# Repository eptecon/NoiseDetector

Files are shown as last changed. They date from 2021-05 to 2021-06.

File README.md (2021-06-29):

NoiseDetector: Connected Noise Detector
======

Noise Detector is a simple device for lowering noise levels in the office or public places. It monitors noise level and alarms when it gets too loud. It is also connected to cloud over Wireless LAN for providing noise data for further analytics
It is easy to install and use in every environment.

### Hardware

Noise Detector is based on a MEMS microphone that measures intensity of noise and ESP32 microcontroller that monitors the noise level and sends measured results to cloud.
The user can adjust a threshold for the detection. The Noise Detector can indicate alarms if it is too loud using onboard buzzer and LED.

### Firmware

The firmware consists of a RTOS and applications for measuring and analysing of noise level as well as sending information to cloud. It connects to a cloud and provides noise data over MQTT.

### Usage

No software installation is required. Just turn on and connect to your WLAN Network. Immediately after connecting, the device starts to send the measured noise level 
to the cloud service ([GlueLogics](https://github.com/eptecon/gluelogics)) enabling analytics for your working environment, even without invasive notifications.

---

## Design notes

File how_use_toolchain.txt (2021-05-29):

ls /dev/cu.*

/dev/ttyUSB0 - UNIX
/dev/cu.SLAB_USBtoUART - MAC

==========
To exit the monitor use shortcut Ctrl+] --- CTRL + ALT + 6
Ctrl-T Ctrl-H will display a help menu with all other keyboard shortcuts.
Any other key apart from Ctrl-] and Ctrl-T is sent through the serial port.
============

Now you can build and flash the application. Run:

make flash

This will compile the application and all the ESP-IDF components, generate bootloader, partition table, and application binaries, and flash these binaries to your ESP32 board.

To see if “hello_world” application is indeed running, type 
make monitor. 
This command is launching IDF Monitor application

To exit monitor use shortcut Ctrl+]. 

To execute make flash and make monitor in one shoot type 
make flash monitor.

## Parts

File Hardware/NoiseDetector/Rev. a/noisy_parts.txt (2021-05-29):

Stückliste exportiert aus /home/erwin/Projekte/eagle/GlueSensors/NoiseSensor/Rev. a/noisy.sch am 11.07.18 14:24

Part Value                   Device                  Package                Description                                                                                       DATASHEET                                     DESCRIPTION DIGIKEY     ELEMENT14 MF      MPN          OC_FARNELL OC_NEWARK OTHER PACKAGE PROD_ID    SF_SKU    SUPPLIER  URL                                                                                            VALUE     
B1   BUZZER-8540S            BUZZER-8540S            BUZZER-8540S                                                                                                                                                                                                                                                                                                                                                                                             
BT1                          BATTERY-AA              BATTERY-AA             Battery - Single Cell                                                                                                                                                                                                                     BATT-08316 PRT-07949                                                                                                                    
C1   1uF/10V(10%)            C-EUC0603               C0603                  CAPACITOR, European symbol                                                                                                                                                                                                                                                                                                                                                        
C2   100nF/10V(10%)          C-EUC0603               C0603                  CAPACITOR, European symbol                                                                                                                                                                                                                                                                                                                                                        
C3   1uF/10V(10%)            C-EUC0603               C0603                  CAPACITOR, European symbol                                                                                                                                                                                                                                                                                                                                                        
C4   1uF/10V(10%)            C-EUC0603               C0603                  CAPACITOR, European symbol                                                                                                                                                                                                                                                                                                                                                        
C5   100nF/10V(10%)          C-EUC0603               C0603                  CAPACITOR, European symbol                                                                                                                                                                                                                                                                                                                                                        
C6   100nF/10V(10%)          C-EUC0603               C0603                  CAPACITOR, European symbol                                                                                                                                                                                                                                                                                                                                                        
C7   100nF/10V(10%)          C-EUC0603               C0603                  CAPACITOR, European symbol                                                                                                                                                                                                                                                                                                                                                        
C8   100nF/10V(10%)          C-EUC0603               C0603                  CAPACITOR, European symbol                                                                                                                                                                                                                                                                                                                                                        
C9   100nF/10V(10%)          C-EUC0603               C0603                  CAPACITOR, European symbol                                                                                                                                                                                                                                                                                                                                                        
C10  100nF/10V(10%)          C-EUC0603               C0603                  CAPACITOR, European symbol                                                                                                                                                                                                                                                                                                                                                        
C11  100nF/10V(10%)          C-EUC0603               C0603                  CAPACITOR, European symbol                                                                                                                                                                                                                                                                                                                                                        
C12  100nF/10V(10%)          C-EUC0603               C0603                  CAPACITOR, European symbol                                                                                                                                                                                                                                                                                                                                                        
C13  100nF/10V(10%)          C-EUC0603               C0603                  CAPACITOR, European symbol                                                                                                                                                                                                                                                                                                                                                        
C14  100n/10V(10%)           C-EUC0603               C0603                  CAPACITOR, European symbol                                                                                                                                                                                                                                                                                                                                                        
C15  1uF/10V(10%)            C-EUC0603               C0603                  CAPACITOR, European symbol                                                                                                                                                                                                                                                                                                                                                        
C16  10uF/25V(10%)           C-EUC0603               C0603                  CAPACITOR, European symbol                                                                                                                                                                                                                                                                                                                                                        
C17  10uF/25V(10%)           C-EUC0603               C0603                  CAPACITOR, European symbol                                                                                                                                                                                                                                                                                                                                                        
C18  1uF/25V(10%)            C-EUC0603               C0603                  CAPACITOR, European symbol                                                                                                                                                                                                                                                                                                                                                        
C19  10uF/25V(10%)           C-EUC0603               C0603                  CAPACITOR, European symbol                                                                                                                                                                                                                                                                                                                                                        
C20  10uF/10V(10%)           C-EUC0603               C0603                  CAPACITOR, European symbol                                                                                                                                                                                                                                                                                                                                                        
C21  100nF/25V(10%)          C-EUC0603               C0603                  CAPACITOR, European symbol                                                                                                                                                                                                                                                                                                                                                        
C22  10uF/25V(10%)           C-EUC0603               C0603                  CAPACITOR, European symbol                                                                                                                                                                                                                                                                                                                                                        
C23  100nF/25V(10%)          C-EUC0603               C0603                  CAPACITOR, European symbol                                                                                                                                                                                                                                                                                                                                                        
C24  100nF/10V(10%)          C-EUC0603               C0603                  CAPACITOR, European symbol                                                                                                                                                                                                                                                                                                                                                        
C25  10uF/10V(10%)           C-EUC0603               C0603                  CAPACITOR, European symbol                                                                                                                                                                                                                                                                                                                                                        
CN3                          USBMINIBLARGE           USB-MINIB_LARGER       USB Connectors                                                                                                                                                                                                                                                                                                                                                                    
D1   MBR120                  MBR0520LT               SOD123                 SCHOTTKY BARRIER RECTIFIER                                                                                                                                                                                                                                                                                                                                                        
D2   4148                    DIODE-BAS16J            SOD-323                Diode                                                                                                                                                                                                                                     DIO-09646                                                                                                                     250mA/100V
H1   STAND-OFF               STAND-OFF               STAND-OFF              Stand Off                                                                                                                                                                                                                                                                                                                                                                         
H2   STAND-OFF               STAND-OFF               STAND-OFF              Stand Off                                                                                                                                                                                                                                                                                                                                                                         
H3   STAND-OFF               STAND-OFF               STAND-OFF              Stand Off                                                                                                                                                                                                                                                                                                                                                                         
LED1 GREEN PWR               LED0805_NOOUTLINE       CHIPLED_0805_NOOUTLINE LED                                                                                                                                                                                                                                                                                                                                                                               
LED2 ORANGE                  LED0805_NOOUTLINE       CHIPLED_0805_NOOUTLINE LED                                                                                                                                                                                                                                                                                                                                                                               
LED3 SML-LX0404              SML-LX0404              LED_RGB                                                                                                                                                                                                                                                                                                                                                                                                  
Q1   N-CHANNEL-MOSFET-BSS138 N-CHANNEL-MOSFET-BSS138 SOT23-3                N-Channel MOSFET Mode Field Effect Transistor                                                     http://www.fairchildsemi.com/ds/BS/BSS138.pdf             BSS138TR-ND 2323154                                                                                          http://au.element14.com/fairchild-semiconductor/bss138/mosfet-n-ch-50v-220ma-sot-23/dp/2323154           
Q2   DMP2045U                MOSFET-P                SOT23-R                P-Channel Mosfet                                                                                                                                                                                                                                                                                                                                                                  
Q3   mmbt2222                TRANSISTOR_NPN          SOT23-R                NPN Transistor                                                                                                                                                                                                                                                                                                                                                                    
Q4   mmbt2222                TRANSISTOR_NPN          SOT23-R                NPN Transistor                                                                                                                                                                                                                                                                                                                                                                    
Q5   DMN2058U                MOSFET-NREFLOW          SOT23-R                N-Channel Mosfet                                                                                                                                                                                                                                                                                                                                                                  
R1   1M(1%)                  R-EU_R0603              R0603                  RESISTOR, European symbol                                                                                                                                                                                                                                                                                                                                                         
R2   1M(1%)                  R-EU_R0603              R0603                  RESISTOR, European symbol                                                                                                                                                                                                                                                                                                                                                         
R3   390(1%)                 R-EU_R0603              R0603                  RESISTOR, European symbol                                                                                                                                                                                                                                                                                                                                                         
R4   10k(1%)                 R-EU_R0603              R0603                  RESISTOR, European symbol                                                                                                                                                                                                                                                                                                                                                         
R5   120k(1%)                R-EU_R0603              R0603                  RESISTOR, European symbol                                                                                                                                                                                                                                                                                                                                                         
R6   10k(1%)                 R-EU_R0603              R0603                  RESISTOR, European symbol                                                                                                                                                                                                                                                                                                                                                         
R7   120k(1%)                R-EU_R0603              R0603                  RESISTOR, European symbol                                                                                                                                                                                                                                                                                                                                                         
R8   100k(1%)                R-EU_R0603              R0603                  RESISTOR, European symbol                                                                                                                                                                                                                                                                                                                                                         
R9   100k(1%)                R-EU_R0603              R0603                  RESISTOR, European symbol                                                                                                                                                                                                                                                                                                                                                         
R10  100k(1%)                R-EU_R0603              R0603                  RESISTOR, European symbol                                                                                                                                                                                                                                                                                                                                                         
R11  470(1%)                 R-EU_R0603              R0603                  RESISTOR, European symbol                                                                                                                                                                                                                                                                                                                                                         
R12  2.2k(1%)                R-EU_R0603              R0603                  RESISTOR, European symbol                                                                                                                                                                                                                                                                                                                                                         
R13  1k(1%)                  R-EU_R0603              R0603                  RESISTOR, European symbol                                                                                                                                                                                                                                                                                                                                                         
R14  10k(1%)                 R-EU_R0603              R0603                  RESISTOR, European symbol                                                                                                                                                                                                                                                                                                                                                         
R15  0(1%)                   R-EU_R0603              R0603                  RESISTOR, European symbol                                                                                                                                                                                                                                                                                                                                                         
R16  10k(1%)                 R-EU_R0603              R0603                  RESISTOR, European symbol                                                                                                                                                                                                                                                                                                                                                         
R17  0(1%)                   R-EU_R0603              R0603                  RESISTOR, European symbol                                                                                                                                                                                                                                                                                                                                                         
R18  10k(1%)                 R-EU_R0603              R0603                  RESISTOR, European symbol                                                                                                                                                                                                                                                                                                                                                         
R19  100k(1%)                R-EU_R0603              R0603                  RESISTOR, European symbol                                                                                                                                                                                                                                                                                                                                                         
R20  100k(1%)                R-EU_R0603              R0603                  RESISTOR, European symbol                                                                                                                                                                                                                                                                                                                                                         
R21  100k(1%)                R-EU_R0603              R0603                  RESISTOR, European symbol                                                                                                                                                                                                                                                                                                                                                         
R22  100k(1%)                R-EU_R0603              R0603                  RESISTOR, European symbol                                                                                                                                                                                                                                                                                                                                                         
R23  10k(1%)                 R-EU_R0603              R0603                  RESISTOR, European symbol                                                                                                                                                                                                                                                                                                                                                         
R24  10k(1%)                 R-EU_R0603              R0603                  RESISTOR, European symbol
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

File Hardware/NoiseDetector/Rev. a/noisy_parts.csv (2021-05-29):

Part | Value | Device | Package | Description | DATASHEET | DESCRIPTION | DIGIKEY | ELEMENT14 | MF | MPN | OC_FARNELL | OC_NEWARK | OTHER | PACKAGE | PROD_ID | SF_SKU | SUPPLIER | URL | VALUE
B1 | BUZZER-8540S | BUZZER-8540S | BUZZER-8540S
BT1 |  | BATTERY-AA | BATTERY-AA | Battery - Single Cell |  |  |  |  |  |  |  |  |  |  | BATT-08316 | PRT-07949
C1 | 1uF/10V(10%) | C-EUC0603 | C0603 | CAPACITOR, European symbol
C2 | 100nF/10V(10%) | C-EUC0603 | C0603 | CAPACITOR, European symbol
C3 | 1uF/10V(10%) | C-EUC0603 | C0603 | CAPACITOR, European symbol
C4 | 1uF/10V(10%) | C-EUC0603 | C0603 | CAPACITOR, European symbol
C5 | 100nF/10V(10%) | C-EUC0603 | C0603 | CAPACITOR, European symbol
C6 | 100nF/10V(10%) | C-EUC0603 | C0603 | CAPACITOR, European symbol
C7 | 100nF/10V(10%) | C-EUC0603 | C0603 | CAPACITOR, European symbol
C8 | 100nF/10V(10%) | C-EUC0603 | C0603 | CAPACITOR, European symbol
C9 | 100nF/10V(10%) | C-EUC0603 | C0603 | CAPACITOR, European symbol
C10 | 100nF/10V(10%) | C-EUC0603 | C0603 | CAPACITOR, European symbol
C11 | 100nF/10V(10%) | C-EUC0603 | C0603 | CAPACITOR, European symbol
C12 | 100nF/10V(10%) | C-EUC0603 | C0603 | CAPACITOR, European symbol
C13 | 100nF/10V(10%) | C-EUC0603 | C0603 | CAPACITOR, European symbol
C14 | 100n/10V(10%) | C-EUC0603 | C0603 | CAPACITOR, European symbol
C15 | 1uF/10V(10%) | C-EUC0603 | C0603 | CAPACITOR, European symbol
C16 | 10uF/25V(10%) | C-EUC0603 | C0603 | CAPACITOR, European symbol
C17 | 10uF/25V(10%) | C-EUC0603 | C0603 | CAPACITOR, European symbol
C18 | 1uF/25V(10%) | C-EUC0603 | C0603 | CAPACITOR, European symbol
C19 | 10uF/25V(10%) | C-EUC0603 | C0603 | CAPACITOR, European symbol
C20 | 10uF/10V(10%) | C-EUC0603 | C0603 | CAPACITOR, European symbol
C21 | 100nF/25V(10%) | C-EUC0603 | C0603 | CAPACITOR, European symbol
C22 | 10uF/25V(10%) | C-EUC0603 | C0603 | CAPACITOR, European symbol
C23 | 100nF/25V(10%) | C-EUC0603 | C0603 | CAPACITOR, European symbol
C24 | 100nF/10V(10%) | C-EUC0603 | C0603 | CAPACITOR, European symbol
C25 | 10uF/10V(10%) | C-EUC0603 | C0603 | CAPACITOR, European symbol
CN3 |  | USBMINIBLARGE | USB-MINIB_LARGER | USB Connectors
D1 | MBR120 | MBR0520LT | SOD123 | SCHOTTKY BARRIER RECTIFIER
D2 | 4148 | DIODE-BAS16J | SOD-323 | Diode |  |  |  |  |  |  |  |  |  |  | DIO-09646 |  |  |  | 250mA/100V
H1 | STAND-OFF | STAND-OFF | STAND-OFF | Stand Off
H2 | STAND-OFF | STAND-OFF | STAND-OFF | Stand Off
H3 | STAND-OFF | STAND-OFF | STAND-OFF | Stand Off
LED1 | GREEN PWR | LED0805_NOOUTLINE | CHIPLED_0805_NOOUTLINE | LED
LED2 | ORANGE | LED0805_NOOUTLINE | CHIPLED_0805_NOOUTLINE | LED
LED3 | SML-LX0404 | SML-LX0404 | LED_RGB
Q1 | N-CHANNEL-MOSFET-BSS138 | N-CHANNEL-MOSFET-BSS138 | SOT23-3 | N-Channel MOSFET Mode Field Effect Transistor | http://www.fairchildsemi.com/ds/BS/BSS138.pdf |  | BSS138TR-ND | 2323154 |  |  |  |  |  |  |  |  |  | http://au.element14.com/fairchild-semiconductor/bss138/mosfet-n-ch-50v-220ma-sot-23/dp/2323154
Q2 | DMP2045U | MOSFET-P | SOT23-R | P-Channel Mosfet
Q3 | mmbt2222 | TRANSISTOR_NPN | SOT23-R | NPN Transistor
Q4 | mmbt2222 | TRANSISTOR_NPN | SOT23-R | NPN Transistor
Q5 | DMN2058U | MOSFET-NREFLOW | SOT23-R | N-Channel Mosfet
R1 | 1M(1%) | R-EU_R0603 | R0603 | RESISTOR, European symbol
R2 | 1M(1%) | R-EU_R0603 | R0603 | RESISTOR, European symbol
R3 | 390(1%) | R-EU_R0603 | R0603 | RESISTOR, European symbol
R4 | 10k(1%) | R-EU_R0603 | R0603 | RESISTOR, European symbol
R5 | 120k(1%) | R-EU_R0603 | R0603 | RESISTOR, European symbol
R6 | 10k(1%) | R-EU_R0603 | R0603 | RESISTOR, European symbol
R7 | 120k(1%) | R-EU_R0603 | R0603 | RESISTOR, European symbol
R8 | 100k(1%) | R-EU_R0603 | R0603 | RESISTOR, European symbol
R9 | 100k(1%) | R-EU_R0603 | R0603 | RESISTOR, European symbol
R10 | 100k(1%) | R-EU_R0603 | R0603 | RESISTOR, European symbol
R11 | 470(1%) | R-EU_R0603 | R0603 | RESISTOR, European symbol
R12 | 2.2k(1%) | R-EU_R0603 | R0603 | RESISTOR, European symbol
R13 | 1k(1%) | R-EU_R0603 | R0603 | RESISTOR, European symbol
R14 | 10k(1%) | R-EU_R0603 | R0603 | RESISTOR, European symbol
R15 | 0(1%) | R-EU_R0603 | R0603 | RESISTOR, European symbol
R16 | 10k(1%) | R-EU_R0603 | R0603 | RESISTOR, European symbol
R17 | 0(1%) | R-EU_R0603 | R0603 | RESISTOR, European symbol
R18 | 10k(1%) | R-EU_R0603 | R0603 | RESISTOR, European symbol
R19 | 100k(1%) | R-EU_R0603 | R0603 | RESISTOR, European symbol
R20 | 100k(1%) | R-EU_R0603 | R0603 | RESISTOR, European symbol
R21 | 100k(1%) | R-EU_R0603 | R0603 | RESISTOR, European symbol
R22 | 100k(1%) | R-EU_R0603 | R0603 | RESISTOR, European symbol
R23 | 10k(1%) | R-EU_R0603 | R0603 | RESISTOR, European symbol
R24 | 10k(1%) | R-EU_R0603 | R0603 | RESISTOR, European symbol
R25 | 1k(1%) | R-EU_R0603 | R0603 | RESISTOR, European symbol
R26 | DNP | R-EU_R0603 | R0603 | RESISTOR, European symbol
R27 | 750(1%) | R-EU_R0603 | R0603 | RESISTOR, European symbol
R28 | 270(1%) | R-EU_R0603 | R0603 | RESISTOR, European symbol
R29 | 330(1%) | R-EU_R0603 | R0603 | RESISTOR, European symbol
R30 | 1k(1%) | R-EU_R0603 | R0603 | RESISTOR, European symbol
R31 | 34(1%) | R-EU_R0603 | R0603 | RESISTOR, European symbol
R32 | 10k(1%) | R-EU_R0603 | R0603 | RESISTOR, European symbol
R33 | DNP | R-EU_R0603 | R0603 | RESISTOR, European symbol
R34 | DNP | R-EU_R0603 | R0603 | RESISTOR, European symbol
R35 | 0(1%) | R-EU_R0603 | R0603 | RESISTOR, European symbol
R36 | 0(1%) | R-EU_R0603 | R0603 | RESISTOR, European symbol
R37 | 10k(1%) | R-EU_R0603 | R0603 | RESISTOR, European symbol
SW1 | SKTDLDE010-T-SWITCH | SKTDLDE010-T-SWITCH | T-SWITCH-ALPS-2
SW2 | SKTDLDE010-T-SWITCH | SKTDLDE010-T-SWITCH | T-SWITCH-ALPS-2
SW3 | SKTDLDE010-T-SWITCH | SKTDLDE010-T-SWITCH | T-SWITCH-ALPS-2
U1 | SPQ0410HR5H | SPQ0410HR5H | SPQ0410HR | MESM microphone
U2 | MCP6022-I/SN | MCP6022-I/SN | SOIC08 | IC OPAMP 2.5V DUAL R-R
U3 | MCP6022-I/SN | MCP6022-I/SN | SOIC08 | IC OPAMP 2.5V DUAL R-R
U4 | LT1966CMS8 | LT1966CMS8 | MSOP8 | Precision Micropower,
U5 | MCP4921-E/SN | MCP4921-E/SN | SOIC8-N_MC | 12 Bit DAC |  | 12 Bit DAC |  |  |  | MCP4921-E/SN | 1332113 | 08J8744 |  | SOIC-8 |  |  | Microchip
U6 | MAX6106EUR | MAX6106EUR | SOT23-3 | VOLTAGE REFERENCE
U7 | ESP-WROOM-03 | ESP-WROOM-03 | ESP-WROOM-03
U8 | AP2112-3.3 | VREG_SOT23-5 | SOT23-5 | SOT23-5 Fixed Voltage Regulators
U9 | MCP73831T-2ACI/OT | MCP73831 | SOT23-5 | MCP73831 Miniature Single-Cell, Fully Integrated Li-Ion, Li-Polymer Charge Management Controllers
U10 | CP2102 | CP2102 | MLP28 | Single-Chip USB to UART Bridge |  |  |  |  | FARNELL | CP2102-GM | 9282130 | 30K5635

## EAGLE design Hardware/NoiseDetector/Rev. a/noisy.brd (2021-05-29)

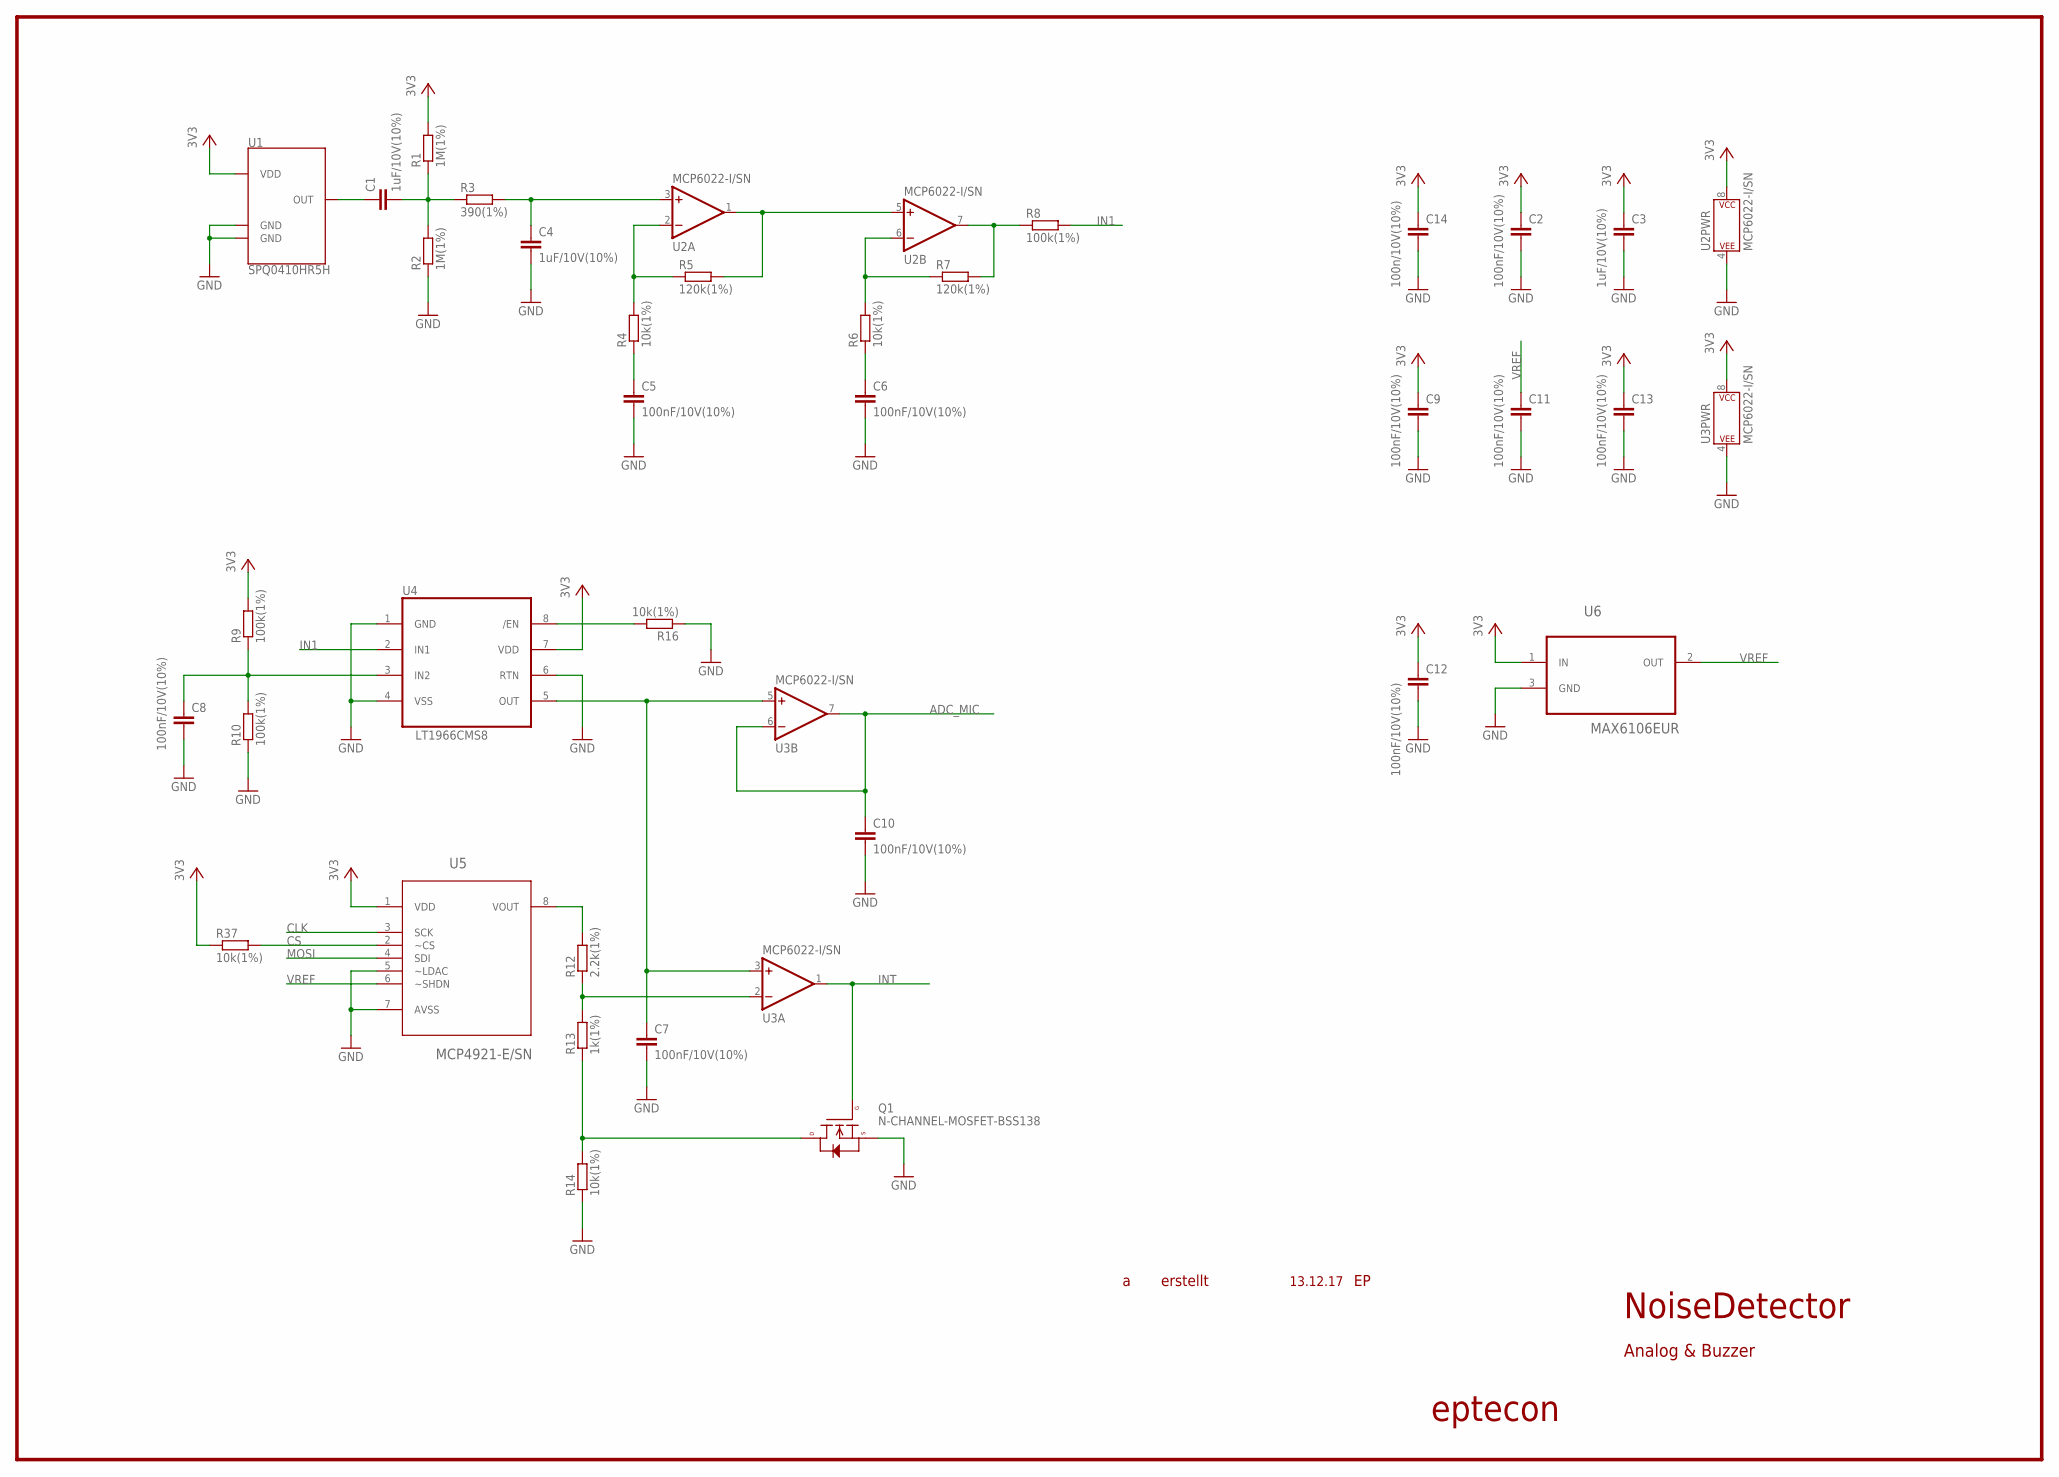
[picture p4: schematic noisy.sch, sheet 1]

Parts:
C1, C3, C4: 1uF/10V(10%); C0603
C2, C5, C6, C7, C8, C9, C10, C11, C12, C13: 100nF/10V(10%); C0603
C14: 100n/10V(10%); C0603
Q1: N-CHANNEL-MOSFET-BSS138; SOT23-3
R1, R2: 1M(1%); R0603
R3: 390(1%); R0603
R4, R6, R14, R16, R37: 10k(1%); R0603
R5, R7: 120k(1%); R0603
R8, R9, R10: 100k(1%); R0603
R12: 2.2k(1%); R0603
R13: 1k(1%); R0603
U1: SPQ0410HR5H; SPQ0410HR
U2, U3: MCP6022-I/SN; SOIC08
U4: LT1966CMS8; MSOP8
U5: MCP4921-E/SN; SOIC8-N_MC
U6: MAX6106EUR; SOT23-3

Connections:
3V3: C2.1, C3.1, C9.1, C12.1, C13.1, C14.1, R1.2, R9.2, R37.1, U1.P$1 (VDD), U2.8 (P$V+), U3.8 (P$V+), U4.7 (VDD), U5.1 (VDD), U6.1 (IN); also elsewhere on the board
ADC_MIC: C10.1, U3.6 (-IN), U3.7 (OUT); also elsewhere on the board
CLK: U5.3 (SCK); also elsewhere on the board
CS: R37.2, U5.2 (~CS); also elsewhere on the board
GND: C2.2, C3.2, C4.2, C5.2, C6.2, C7.2, C8.2, C9.2, C10.2, C11.2, C12.2, C13.2, C14.2, Q1.2 (S), R2.1, R10.1, R14.1, R16.1, U1.P$2 (GND), U1.P$3 (GND), U2.4 (P$V-), U3.4 (P$V-), U4.1 (GND), U4.4 (VSS), U4.6 (RTN), U5.5 (~LDAC), U5.7 (AVSS), U6.3 (GND); also elsewhere on the board
IN1: R8.2, U4.2 (IN1)
INT: Q1.1 (G), U3.1 (OUT); also elsewhere on the board
MOSI: U5.4 (SDI); also elsewhere on the board
unnamed: C1.1, U1.P$4 (OUT)
unnamed: C1.2, R1.1, R2.2, R3.1
unnamed: C4.1, R3.2, U2.3 (+IN)
unnamed: R4.2, R5.1, U2.2 (-IN)
unnamed: C5.1, R4.1
unnamed: R5.2, U2.1 (OUT), U2.5 (+IN)
unnamed: R6.2, R7.1, U2.6 (-IN)
unnamed: C6.1, R6.1
unnamed: R7.2, R8.1, U2.7 (OUT)
unnamed: C8.1, R9.1, R10.2, U4.3 (IN2)
unnamed: R12.2, U5.8 (VOUT)
unnamed: R12.1, R13.2, U3.2 (-IN)
unnamed: Q1.3 (D), R13.1, R14.2
unnamed: C7.1, U3.3 (+IN), U3.5 (+IN), U4.5 (OUT)
unnamed: R16.2, U4.8 (/EN)
VREF: C11.1, U5.6 (~SHDN), U6.2 (OUT)

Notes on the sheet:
NoiseDetector
Analog & Buzzer
eptecon
erstellt
13.12.17

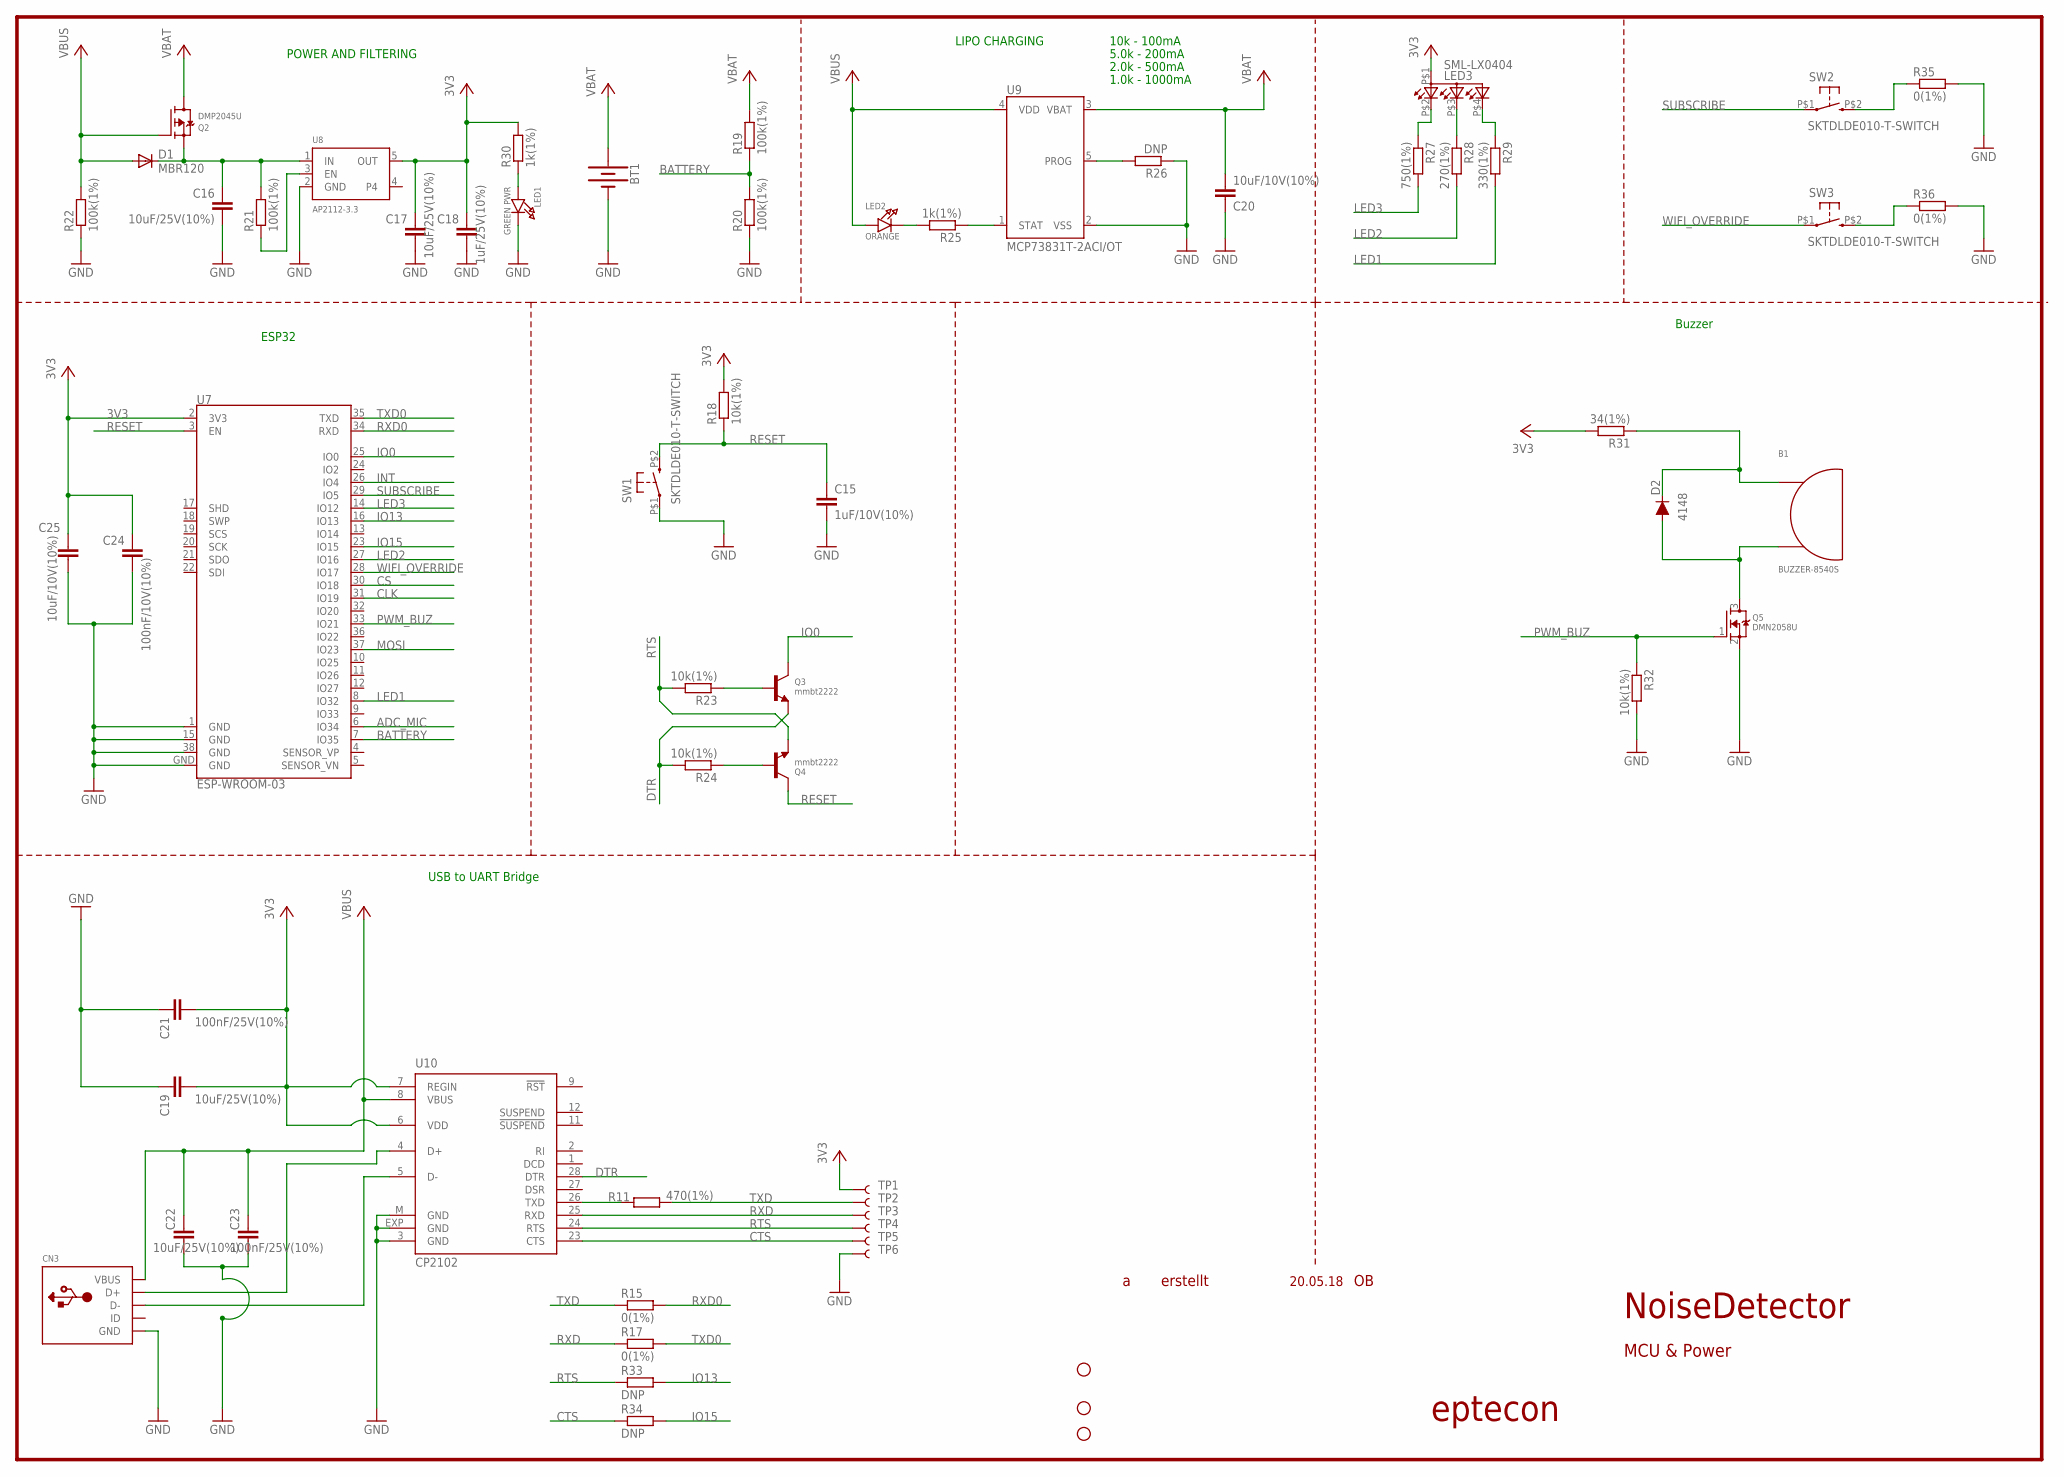
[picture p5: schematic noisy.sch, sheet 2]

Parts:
B1: BUZZER-8540S
BT1: BATTERY-AA
C15: 1uF/10V(10%); C0603
C16, C17, C19, C22: 10uF/25V(10%); C0603
C18: 1uF/25V(10%); C0603
C20, C25: 10uF/10V(10%); C0603
C21, C23: 100nF/25V(10%); C0603
C24: 100nF/10V(10%); C0603
CN3: USBMINIBLARGE; USB-MINIB_LARGER
D1: MBR120; SOD123
D2: 4148; SOD-323
H1, H2, H3: STAND-OFF
LED1: GREEN PWR; CHIPLED_0805_NOOUTLINE
LED2: ORANGE; CHIPLED_0805_NOOUTLINE
LED3: SML-LX0404; LED_RGB
Q2: DMP2045U; SOT23-R
Q3, Q4: mmbt2222; SOT23-R
Q5: DMN2058U; SOT23-R
R11: 470(1%); R0603
R15, R17, R35, R36: 0(1%); R0603
R18, R23, R24, R32: 10k(1%); R0603
R19, R20, R21, R22: 100k(1%); R0603
R25, R30: 1k(1%); R0603
R26, R33, R34: DNP; R0603
R27: 750(1%); R0603
R28: 270(1%); R0603
R29: 330(1%); R0603
R31: 34(1%); R0603
SW1, SW2, SW3: SKTDLDE010-T-SWITCH; T-SWITCH-ALPS-2
TP1, TP2, TP3, TP4, TP5, TP6: TEST-POINT3X5; PAD.03X.05
U7: ESP-WROOM-03
U8: AP2112-3.3; SOT23-5
U9: MCP73831T-2ACI/OT; SOT23-5
U10: CP2102; MLP28

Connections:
3V3: C17.1, C18.1, C19.2, C21.2, C24.1, C25.1, LED3.P$1 (A2), R18.2, R30.2, R31.2, TP1.P$1, U7.2 (3V3), U8.5 (OUT), U10.6 (VDD), U10.7 (REGIN); also elsewhere on the board
ADC_MIC: U7.6 (IO34); also elsewhere on the board
BATTERY: R19.1, R20.2, U7.7 (IO35)
CLK: U7.31 (IO19); also elsewhere on the board
CS: U7.30 (IO18); also elsewhere on the board
CTS: R34.1, TP5.P$1, U10.23 (CTS)
DTR: Q3.2 (E), R24.2, U10.28 (DTR)
GND: BT1.GND@1 (-), C15.2, C16.2, C17.2, C18.2, C19.1, C20.1, C21.1, C22.1, C23.1, C24.2, C25.2, CN3.GND, LED1.C, Q5.2 (S), R20.1, R22.1, R26.1, R32.2, R35.2, R36.2, SW1.P$1 (1), TP6.P$1, U7.1 (GND), U7.15 (GND), U7.38 (GND), U7.GND, U8.2 (GND), U9.2 (VSS), U10.3 (GND), U10.EXP (GND), U10.M (GND); also elsewhere on the board
INT: U7.26 (IO4); also elsewhere on the board
IO0: Q3.3 (C), U7.25 (IO0)
IO13: R33.2, U7.16 (IO13)
IO15: R34.2, U7.23 (IO15)
LED1: R29.2, U7.8 (IO32)
LED2: R28.2, U7.27 (IO16)
LED3: R27.2, U7.14 (IO12)
MOSI: U7.37 (IO23); also elsewhere on the board
unnamed: C16.1, D1.C, Q2.2 (S), R21.2, U8.1 (IN)
unnamed: Q4.1 (B), R24.1
unnamed: R11.1, U10.26 (TXD)
unnamed: Q3.1 (B), R23.1
unnamed: CN3.D+, U10.4 (D+)
unnamed: CN3.D-, U10.5 (D-)
unnamed: R35.1, SW2.P$2 (3)
unnamed: R36.1, SW3.P$2 (3)
unnamed: LED3.P$2 (CRED), R27.1
unnamed: R25.1, U9.1 (STAT)
unnamed: LED2.C, R25.2
unnamed: LED3.P$3 (CBLUE), R28.1
unnamed: LED3.P$4 (CGREEN), R29.1
unnamed: R26.2, U9.5 (PROG)
unnamed: R21.1, U8.3 (EN)
unnamed: LED1.A, R30.1
unnamed: B1.PLUS, D2.C, R31.1
unnamed: B1.MINUS, D2.A, Q5.3 (D)
PWM_BUZ: Q5.1 (G), R32.1, U7.33 (IO21)
RESET: C15.1, Q4.3 (C), R18.1, SW1.P$2 (3), U7.3 (EN)
RTS: Q4.2 (E), R23.2, R33.1, TP4.P$1, U10.24 (RTS)
RXD: R17.1, TP3.P$1, U10.25 (RXD)
RXD0: R15.2, U7.34 (RXD)
SUBSCRIBE: SW2.P$1 (1), U7.29 (IO5)
TXD: R11.2, R15.1, TP2.P$1
TXD0: R17.2, U7.35 (TXD)
VBAT: BT1.PWR@1 (+), C20.2, Q2.3 (D), R19.2, U9.3 (VBAT)
VBUS: C22.2, C23.2, CN3.VBUS, D1.A, LED2.A, Q2.1 (G), R22.2, U9.4 (VDD), U10.8 (VBUS)
WIFI_OVERRIDE: SW3.P$1 (1), U7.28 (IO17)

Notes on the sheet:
NoiseDetector
MCU & Power
eptecon
erstellt
20.05.18
ESP32
POWER AND FILTERING
USB to UART Bridge
LIPO CHARGING
10k - 100mA
5.0k - 200mA
2.0k - 500mA
1.0k - 1000mA
Buzzer

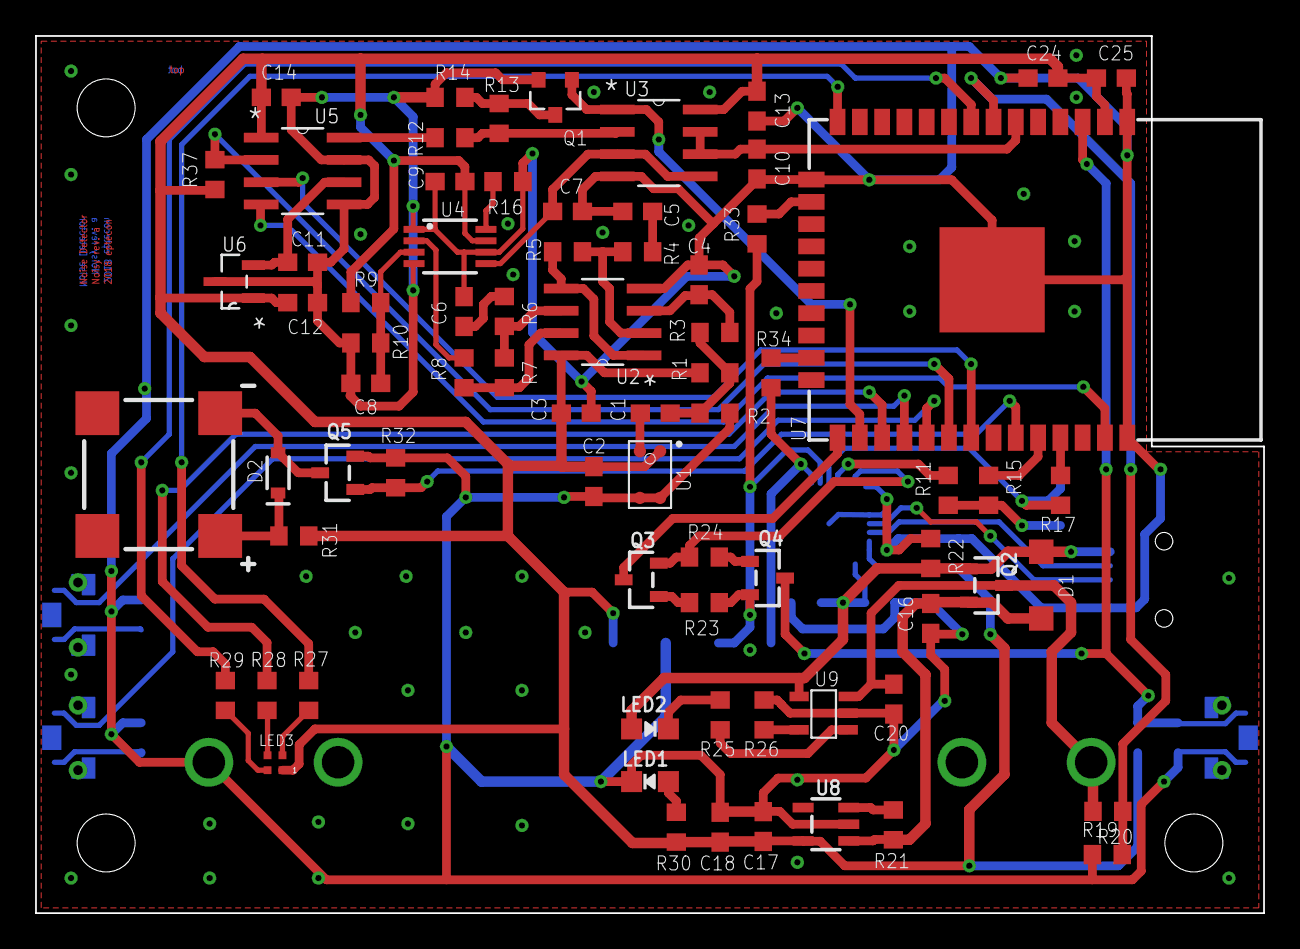
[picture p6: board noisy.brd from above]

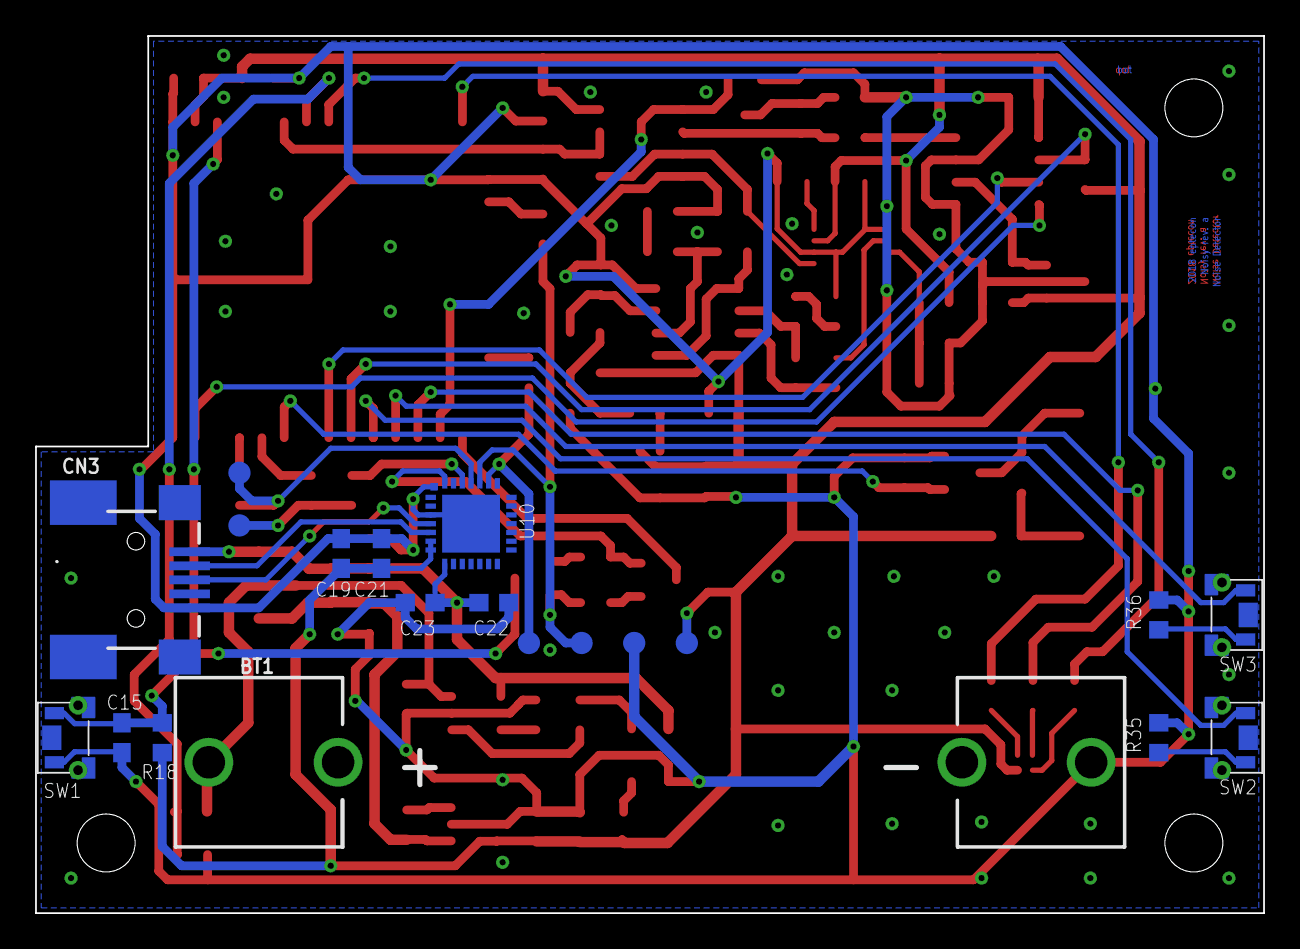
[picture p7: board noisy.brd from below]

Board: 2 copper layers, 70.0 x 50.0 mm, 97 parts (20 on the bottom side), 62 nets.

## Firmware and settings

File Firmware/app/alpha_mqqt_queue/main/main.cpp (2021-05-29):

// Created by Oleksandra Baga on 06.02.18.
// Eptecon Berlin

#include <stdio.h>
#include <stdlib.h>
#include <string.h>
#include <time.h>
#include <unistd.h>
#include "freertos/FreeRTOS.h"
#include "driver/gpio.h"
#include "soc/gpio_struct.h"
#include "driver/spi_master.h"
#include "esp_system.h"
#include "freertos/task.h"
#include "freertos/queue.h"

#include "BootWiFi.h"
#include "sdkconfig.h"
#include "spi_app.h"
#include "interrupt_app.h"
#include "adc_app.h"
#include "pwm_app.h"
#include "mqtt_publish.h"
#include "queue_int.h"
#include "interrupt.h"


BootWiFi *boot;
clock_t start_t;

extern "C" {
void app_main(void);
}

void app_main(void){

    /*********************************************************************************
    * Queue for Interrupts and Time Scheduling
    *********************************************************************************/
    queueInterrupt = q_new();
    start_t = clock();
    printf("Starting of the program, start_t = %ld\n", start_t);

    /*********************************************************************************
    * WI-FI
    *********************************************************************************/
    boot = new BootWiFi();
    boot->boot();

    /*********************************************************************************
     * GPIOs Matrix Init
     *********************************************************************************/
    // SPI GPIO
    gpio_config_input(&io_int_conf);
    gpio_init_noise_ISR();
    // LED GPIO
    blink_interupt_init();
    // PWM GPIO
    pwm_gpio_init();

    /*********************************************************************************
     * ADC Init
     *********************************************************************************/
    adc_init(&characteristics);

    /*********************************************************************************
     * SPI Init
     *********************************************************************************/
    spi_to_noise_click_bus_init(&buscfg);
    spi_to_noise_click_slave_init(&devcfg, &spi);
    // Transmit the V_in to the SPI
    spi_to_noise_click_transmit_cmd(spi);

    /*********************************************************************************
    * PWM Config and Init
    *********************************************************************************/
    pwm_modul_config(&pwm_config);

    /*********************************************************************************
    * JSON Creation and Tracking
    *********************************************************************************/
    mqtt_msg = mqtt_create_json();
    mqtt_msg = mqtt_create_json_voltage();

    /*********************************************************************************
     * RTOS Tasks
     *********************************************************************************/
    // ISR Task
    xTaskCreate(gpio_noise_interrupt_task, "Interrupt from the Noise Click on the GPIO", 2048, NULL, 10, NULL);

    // Blink LED Task
    xTaskCreate(blink_interrupt_task, "blink task", configMINIMAL_STACK_SIZE, NULL, 5, NULL);

    // PWM for Buzzer Task
    xTaskCreate(pwm_buzzer_task, "pwm buzzer task", 4096, NULL, 5, NULL);

    // Updating JSON via MQTT if interrupt occurred
    xTaskCreate(mqtt_interrupt_task, "JSON via MQTT", 8192, NULL, 5, NULL);

    printf("Running.\n");
}

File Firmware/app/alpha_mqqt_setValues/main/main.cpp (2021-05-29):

// Created by Oleksandra Baga on 06.02.18.
// Eptecon Berlin

#include <stdio.h>
#include <stdlib.h>
#include <string.h>
#include <time.h>
#include <unistd.h>
#include "freertos/FreeRTOS.h"
#include "driver/gpio.h"
#include "soc/gpio_struct.h"
#include "driver/spi_master.h"
#include "esp_system.h"
#include "freertos/task.h"
#include "freertos/queue.h"

#include "BootWiFi.h"
#include "sdkconfig.h"
#include "spi_app.h"
#include "interrupt_app.h"
#include "adc_app.h"
#include "pwm_app.h"
#include "mqtt_publish.h"
#include "mqtt_subscribe.h"
#include "queue_int.h"
#include "interrupt.h"
#include "battery.h"


BootWiFi *boot;
clock_t start_t;

TaskHandle_t xBlinkTaskHandle = NULL;
TaskHandle_t xPWMTaskHandle = NULL;


extern "C" {
void app_main(void);
}

void app_main(void){

    /*********************************************************************************
    * WI-FI
    *********************************************************************************/
    boot = new BootWiFi();
    boot->boot();

    /*********************************************************************************
    * Queue for Interrupts and Time Scheduling
    *********************************************************************************/
    queueInterrupt = q_new();
    printf("Starting of the program, start_t = %ld\n", clock());

    /*********************************************************************************
     * GPIOs Matrix Init
     *********************************************************************************/
    // Config GPIOs for ISR as Input:
    // New buttons with ISR should be added here.
    // Interrupt from Noise Click
    // Button for MQTT Subscription
    gpio_config_input(&io_int_conf);

    // create a Queue for ISR and hook an ISR Handler
    gpio_init_noise_ISR();

    // LED GPIO as Output without ISR
    blink_interupt_init();
    // PWM GPIO without ISR
    pwm_gpio_init();

    /*********************************************************************************
     * ADC Init
     *********************************************************************************/
    adc_init(&characteristics);

    /*********************************************************************************
     * SPI Init
     *********************************************************************************/
    spi_to_noise_click_bus_init(&buscfg);
    spi_to_noise_click_slave_init(&devcfg, &spi);
    // Transmit the V_in to the SPI
    spi_to_noise_click_transmit_cmd(spi, V_IN_NOISE_CLICK);

    /*********************************************************************************
    * PWM Config and Init
    *********************************************************************************/
    pwm_modul_config(&pwm_config);

    /*********************************************************************************
    * JSON Creation and Tracking
    *********************************************************************************/
    mqtt_msg = mqtt_create_json();
    mqtt_msg = mqtt_create_json_voltage();
    mqtt_msg = mqtt_create_json_led();
    mqtt_msg = mqtt_create_json_buzzer();
    mqtt_msg = mqtt_create_json_battery();
    mqtt_create_json_threshold();

    /*********************************************************************************
     * RTOS Tasks
     *********************************************************************************/
    // ISR Tasks: Noise Interrupt and Button Detection
    xTaskCreate(gpio_noise_interrupt_task, "Interrupt from the Noise Click on the GPIO", 2048, NULL, 10, NULL);
    xTaskCreate(gpio_button_subscribe_interrupt_task, "Interrupt from button",8192, NULL, 10, NULL);

    // Blink LED Task
    xTaskCreate(blink_interrupt_task, "blink task", configMINIMAL_STACK_SIZE, NULL, 5, &xBlinkTaskHandle);
    mqtt_update_json_led();

    // PWM for Buzzer Task
    xTaskCreate(pwm_buzzer_task, "pwm buzzer task", 4096, NULL, 5, &xPWMTaskHandle);
    mqtt_update_json_buzzer();

    // Updating JSON via MQTT if interrupt occurred
    xTaskCreate(mqtt_interrupt_task, "JSON via MQTT", 8192, NULL, 5, NULL);

    // Json default factory setting publish
    mqtt_publish((char*) TOPIC2, mqtt_msg);

    printf("RUNNING!\n");

}

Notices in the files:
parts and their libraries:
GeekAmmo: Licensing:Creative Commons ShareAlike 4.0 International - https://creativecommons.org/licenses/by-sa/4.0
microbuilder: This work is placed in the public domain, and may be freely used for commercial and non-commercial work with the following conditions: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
